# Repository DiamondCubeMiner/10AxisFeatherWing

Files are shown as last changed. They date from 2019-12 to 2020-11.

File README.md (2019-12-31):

# 10AxisFeatherWing #
A 10-DOF Featherwing, powered by BNO055 and BME280.

## Description ##
This featherwing uses I2C to connect both the IMU (BNO055) and the altimeter (BME280) to the Feather.
I made this to design projects that require a 10-DOF IMU in a tiny package where breakouts can affect the weight a lot and may not be a good option, such as a quadcopter, a model plane, or a model rocket.

## Drivers ##
This project is designed to use [Adafruit Unified Sensor Drivers](https://github.com/adafruit/Adafruit_Sensor).
  - [Adafruit_BNO055](https://github.com/adafruit/Adafruit_BNO055)
  - [Adafruit_BME280_Library](https://github.com/adafruit/Adafruit_BME280_Library/)

## Thanks ##
This project is derived from the following projects:
  - [Adafruit-ADXL343-ADT7410-Featherwing-PCB](https://github.com/adafruit/Adafruit-ADXL343-ADT7410-Featherwing-PCB)
  - [Adafruit-BNO055-Breakout-PCB](https://github.com/adafruit/Adafruit-BNO055-Breakout-PCB)
  - [Adafruit-BME280-Breakout-PCB](https://github.com/adafruit/Adafruit-BME280-Breakout-PCB)

Thanks to Adafruit for their open-source schematics!

Thanks to ppelleti for the awesome FeatherWing Template!

[FeatherWing-template-KiCad](https://github.com/ppelleti/FeatherWing-template-KiCad)

## License ##
This work is licensed under the Creative Commons Attribution-ShareAlike 3.0 Unported License. To view a copy of this license, visit http://creativecommons.org/licenses/by-sa/3.0/ or by opening license.txt included in this project.

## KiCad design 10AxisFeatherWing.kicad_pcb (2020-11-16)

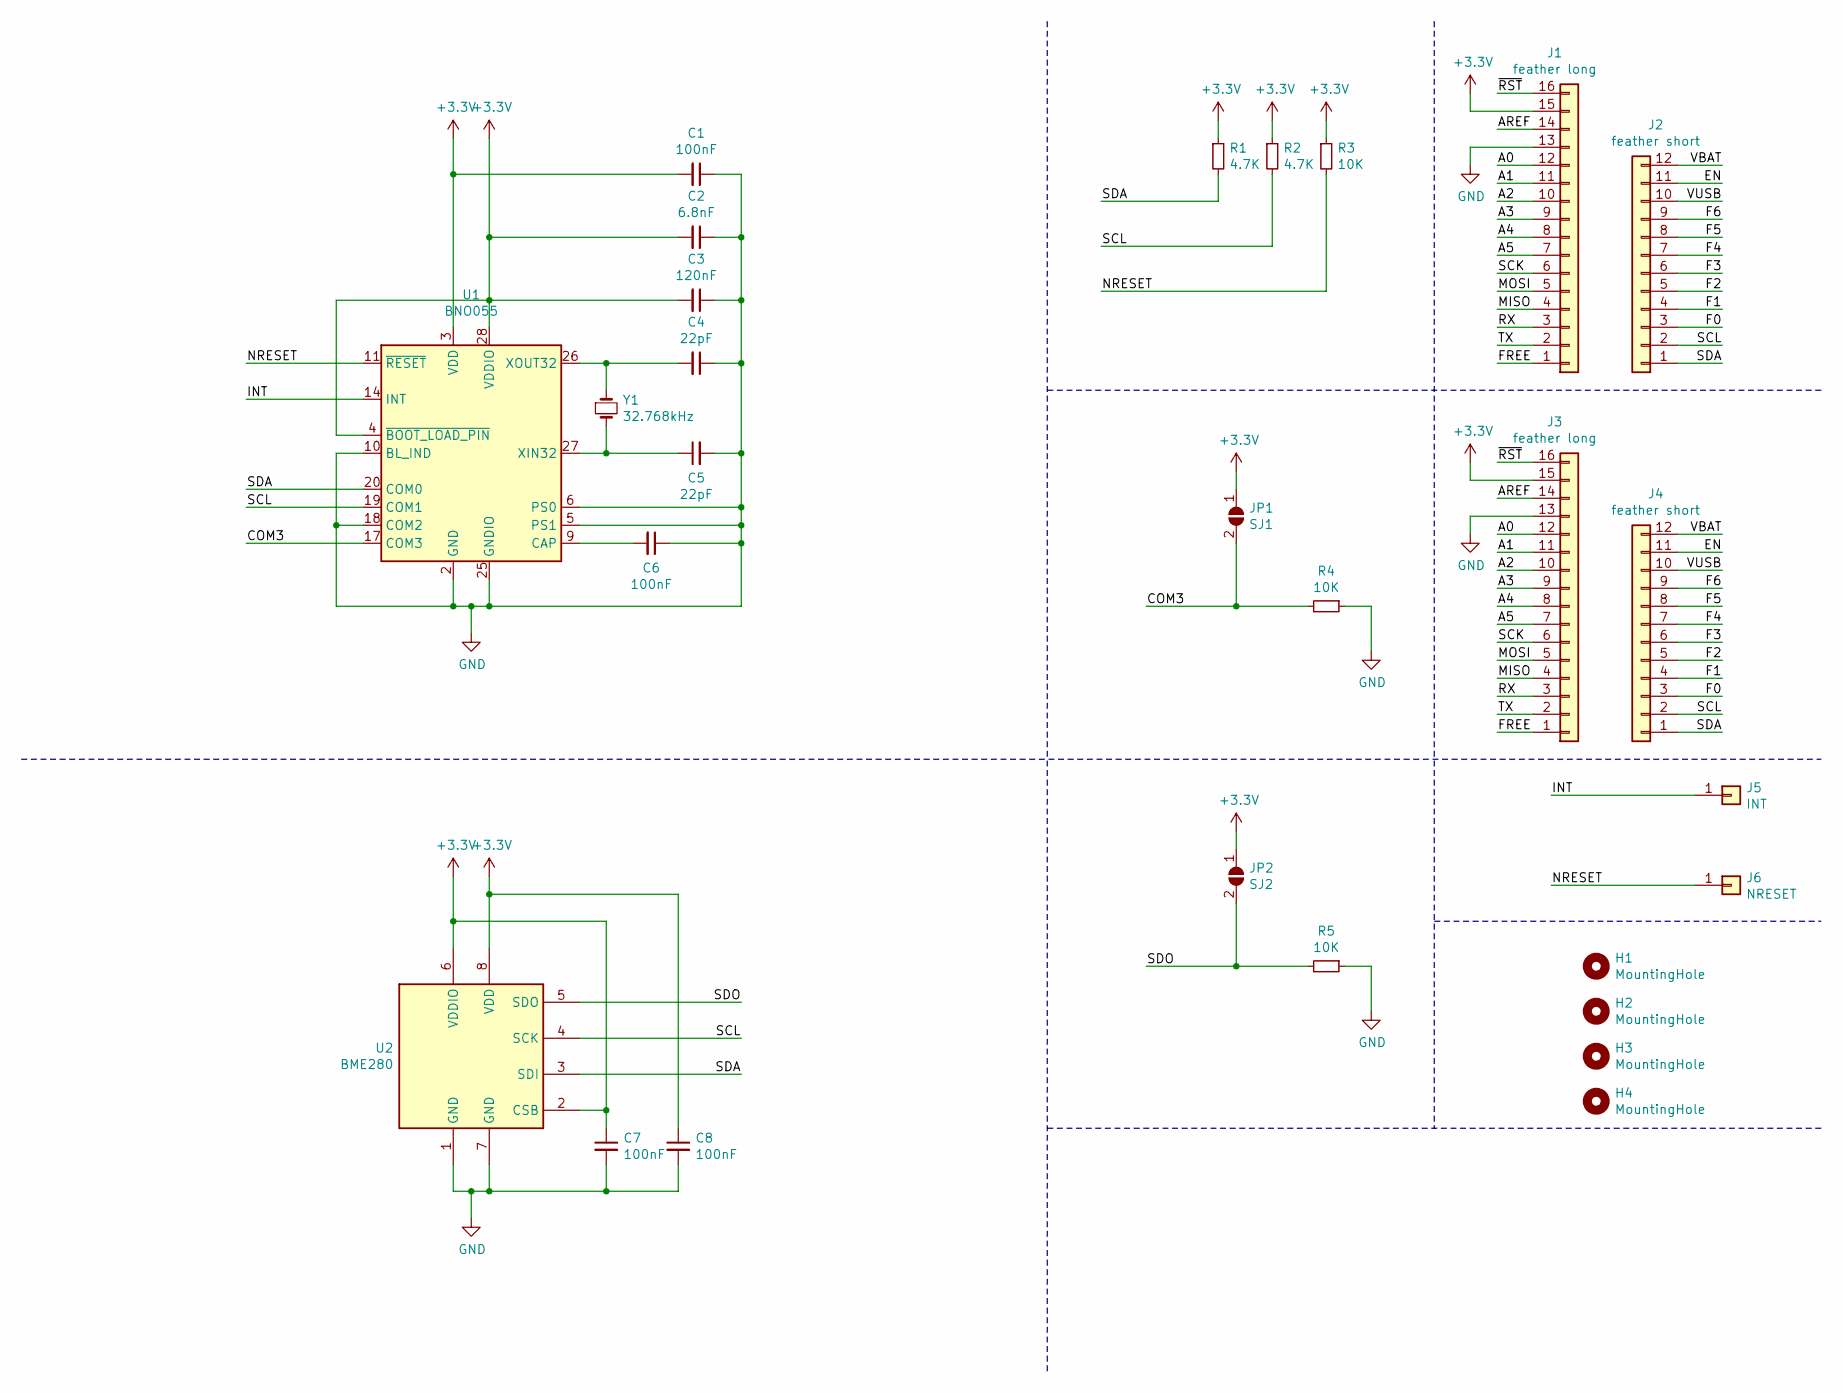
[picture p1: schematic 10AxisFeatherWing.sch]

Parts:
C1, C6, C7, C8: 100nF; C_0603_1608Metric
C2: 6.8nF; C_0603_1608Metric
C3: 120nF; C_0603_1608Metric
C4, C5: 22pF; C_0603_1608Metric
H1, H2, H3, H4: MountingHole; MountingHole_2.7mm_M2.5
J1: feather long; PinHeader_1x16_P2.54mm_Vertical
J2: feather short; PinHeader_1x12_P2.54mm_Vertical
J3: feather long; PinSocket_1x16_P2.54mm_Vertical
J4: feather short; PinSocket_1x12_P2.54mm_Vertical
J5: INT; SolderWirePad_1x01_Drill0.8mm
J6: NRESET; SolderWirePad_1x01_Drill0.8mm
JP1: SJ1; SolderJumper-2_P1.3mm_Open_Pad1.0x1.5mm
JP2: SJ2; SolderJumper-2_P1.3mm_Open_Pad1.0x1.5mm
R1, R2: 4.7K; R_0603_1608Metric
R3, R4, R5: 10K; R_0603_1608Metric
U1: BNO055; LGA-28_5.2x3.8mm_P0.5mm
U2: BME280; Bosch_LGA-8_2.5x2.5mm_P0.65mm_ClockwisePinNumbering
Y1: 32.768kHz; Crystal_SMD_3215-2Pin_3.2x1.5mm

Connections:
+3V3: C1.2, C2.2, C3.2, C7.1, C8.1, J1.15, J3.15, JP1.1 (A), JP2.1 (A), R1.1, R2.1, R3.1, U1.3 (VDD), U1.4 (~BOOT_LOAD_PIN), U1.28 (VDDIO), U2.2 (CSB), U2.6 (VDDIO), U2.8 (VDD)
/A0: J1.12, J3.12
/A1: J1.11, J3.11
/A2: J1.10, J3.10
/A3: J1.9, J3.9
/A4: J1.8, J3.8
/A5: J1.7, J3.7
/AREF: J1.14, J3.14
/COM3: JP1.2 (B), R4.2, U1.17 (COM3)
/EN: J2.11, J4.11
/F0: J2.3, J4.3
/F1: J2.4, J4.4
/F2: J2.5, J4.5
/F3: J2.6, J4.6
/F4: J2.7, J4.7
/F5: J2.8, J4.8
/F6: J2.9, J4.9
/FREE: J1.1, J3.1
/INT: J5.1, U1.14 (INT)
/MISO: J1.4, J3.4
/MOSI: J1.5, J3.5
/NRESET: J6.1, R3.2, U1.11 (~RESET)
/RX: J1.3, J3.3
/SCK: J1.6, J3.6
/SCL: J2.2, J4.2, R2.2, U1.19 (COM1), U2.4 (SCK)
/SDA: J2.1, J4.1, R1.2, U1.20 (COM0), U2.3 (SDI)
/SDO: JP2.2 (B), R5.2, U2.5 (SDO)
/TX: J1.2, J3.2
/VBAT: J2.12, J4.12
/VUSB: J2.10, J4.10
/~RST: J1.16, J3.16
GND: C1.1, C2.1, C3.1, C4.1, C5.2, C6.1, C7.2, C8.2, J1.13, J3.13, R4.1, R5.1, U1.2 (GND), U1.5 (PS1), U1.6 (PS0), U1.10 (BL_IND), U1.15 (GNDIO), U1.16 (GNDIO), U1.18 (COM2), U1.25 (GNDIO), U2.1 (GND), U2.7 (GND)
unnamed: C4.2, U1.26 (XOUT32), Y1.1
unnamed: C5.1, U1.27 (XIN32), Y1.2
unnamed: C6.2, U1.9 (CAP)

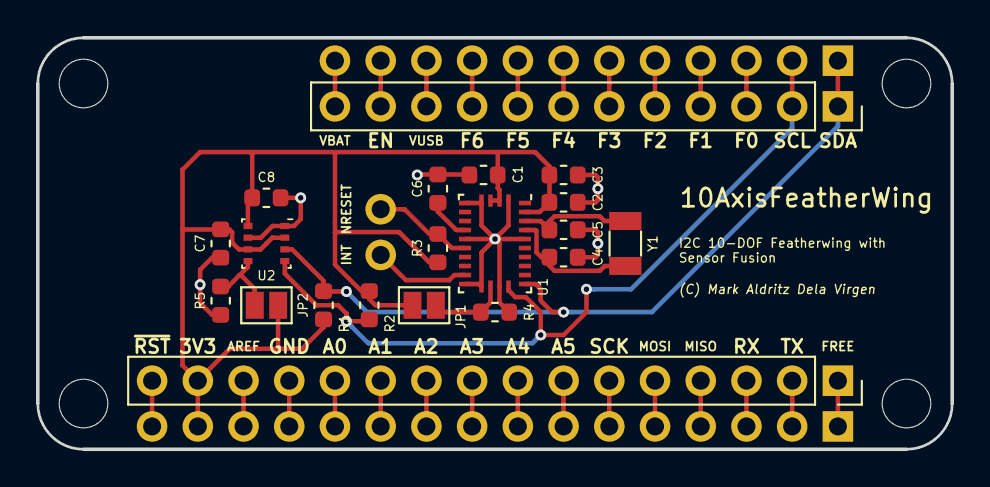
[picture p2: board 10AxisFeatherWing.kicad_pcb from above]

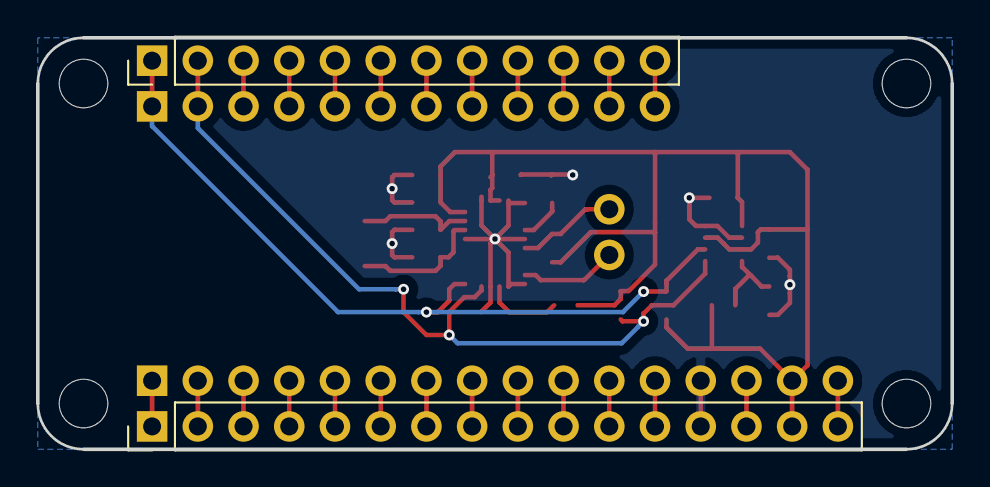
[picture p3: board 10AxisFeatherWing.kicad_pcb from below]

Board: 2 copper layers, 50.8 x 22.9 mm, 28 parts (2 on the bottom side), 35 nets.

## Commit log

2019-12-20 Initial upload
    [10AxisFeatherWing.brd, 10AxisFeatherWing.sch]
2019-12-22 Fixed IMU VDDIO not connected
    [10AxisFeatherWing.brd, 10AxisFeatherWing.sch]
2019-12-24 Added new features
    Added RESET button, INT breakout, and silk text.
    [10AxisFeatherWing.brd, 10AxisFeatherWing.sch]
2019-12-26 Corrected crystal capacitor values
    [10AxisFeatherWing.brd, 10AxisFeatherWing.sch]
2019-12-31 Migration to KiCad
    [10AxisFeatherWing.kicad_pcb, 10AxisFeatherWing.sch]
2020-01-05 Updated features
    Replaced NRESET with pin instead of a button, Added silk text
    [10AxisFeatherWing.kicad_pcb, 10AxisFeatherWing.sch]
2020-01-07 Minor format fix
    [10AxisFeatherWing.kicad_pcb, 10AxisFeatherWing.sch]
2020-01-12 Increased trace width
    [10AxisFeatherWing.kicad_pcb, 10AxisFeatherWing.sch]
2020-01-13 Updated PCB
    [10AxisFeatherWing.kicad_pcb]
2020-02-06 Fixed electrical connections
    Fixed the following electrical connection errors:
    > Pin 6 on BNO055 not connected to GND
    > SDA and SCL vias too close
    > Pin 18 on BNO055 GND relocated
    [10AxisFeatherWing.kicad_pcb]
2020-02-06 Removed STEMMA connector
    STEMMA connectors should have 3.3V to 5V level shifting and power regulation.
    This board does not have those features, so they were removed.
    [10AxisFeatherWingLE.kicad_pcb, 10AxisFeatherWingLE.sch]
2020-02-06 Revert "Removed STEMMA connector"
    This reverts commit 5727fb72f54931faedf32c304c5adffcc3f247c0.
    [10AxisFeatherWingLE.kicad_pcb, 10AxisFeatherWingLE.sch]
2020-02-07 Fixed C7 not connected to BME280 pin 6
    C7 is a decoupling capacitor, and should be connected to both VDD.
    [10AxisFeatherWing.kicad_pcb]
2020-09-23 EagleCAD Refactor
    - Switched to EagleCAD. Now uses microbuilder.lbr used by Adafruit Industries
    - Removed filter caps
    - Added STEMMA connector
    - Adafruit Logo! Heavily based on their latest 9-DoF Combo featherwings (Should I remove it?)
    [10AxisFeatherWing.brd, 10AxisFeatherWing.kicad_pcb, 10AxisFeatherWing.sch]
2020-11-12 Revert "EagleCAD Refactor"
    This reverts commit e0a2de9822f84c03f4477eba47b3f3700a9858d7.
    [10AxisFeatherWing.brd, 10AxisFeatherWing.kicad_pcb, 10AxisFeatherWing.sch]
2020-11-16 I2C pull-up resistor fix
    Changed I2C pull-up resistor values from 10K to 4.7K
    [10AxisFeatherWing.kicad_pcb, 10AxisFeatherWing.sch]
